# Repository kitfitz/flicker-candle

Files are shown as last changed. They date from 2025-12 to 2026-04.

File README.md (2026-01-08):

# Antique inspired candlestick holder
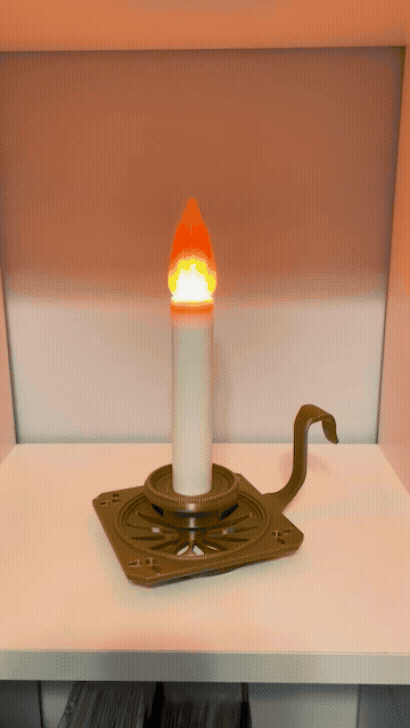
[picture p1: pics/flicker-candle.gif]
Flickering LED candle video


This project started with a restoration and modernization to an antique candlestick holder
that my grandfather made. I adoped some of the design elements as an homage to his work,
but used a style all my own. The sections below detail each aspect required to build your
own copy and a bit more about the history for those interested.

## Electrical components

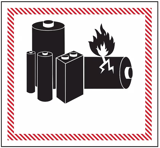
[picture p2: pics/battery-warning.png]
Battery Danger warning label

</br>**DANGER**: Lithium Ion batteries can get hot
and cause a fire!

The battery and charger used are specified to detect short conditions and overheading, but
always use caution when working with these devices!

The design choices were influenced by size and common availability. Everything is available
through Amazon, maybe other channels. The electrical components are [here](electrical/electrical.md)

The LED bulb uses a standard 12v G4 socket. There is a charger for the single LiPo cell
and a DC to DC converter to boost the battery voltage to 12v.

## 3D models

There are [six 3D printed parts](3D-cad/parts.md), designed using [OpenSCAD](https://openscad.org/).
All of the designs are my original work and I'm not a mechanical designer, so don't be
too hard on me if the models aren't great!

The parts were printed using a Prusa Research i3 MK3S using PrusaSlicer. I tend to make
models with tight clearances and sand as necessary. The inside of the bulb needed a
bit of work to make the LED fit. There isn't enough thickness to make the inside
bigger without getting into the threads. Hand filing the inside diameter was the best
solution I found.

The bulb is printed in Prusament PETG Prusa Orange transparent. The base and cup are
printed in Panchroma PLA Silk Brass. The candle, charge plate, and latch are printed in
Amolen PLA+ Paper White.

## Assembly

The candle has 14 individual parts, with assembly instructions [here](assembly/assembly.md)

## More about the history and design

In the house where I grew up, as you entered through the front door you stood in a foyer.
Towards the other end, by the hallway leading to the bedrooms, was a small round table.
On the table was a nightlight, hand crafted by my grandfather, that resembled a
candlestick holder with a candle and a neon flicker bulb on top. He likely cast the
intricate brass base piece in his basement. The family moved out of that house and in the
process of moving (multiple times), the candle holder was damaged. The handle was broken
off the base and into two pieces. Eventually the candle and electrical parts were lost.
My sister suggested that without the original parts, maybe I could make something to
replace them. The project became somewhat like what the car world calls a "restomod."
The idea being you preserve the antique style and as much of the original as makes sense
(restore), but use modern parts for the engine, brakes, handling, and so forth (modify).
In the case of an antique electric candle, that means a rechargeable battery and an LED
flicker bulb are basic requirements.

When grandad made his candle, he didn\'t make a cup. The white candle tube went all the
way to the base, with an electrical cord coming through a cutout at the bottom. My candle
design is the same form factor as a standard 7/8 in. (22mm) taper candle, which requires a
cup feature. Researching the design in different periods led to see that grandad was a
fan of the 18th Century Victorian style. The beaded ring feature is from that period and
was kept in the cup design to echo the base. The base I designed kept the beaded ring
feature, but has a simple flower theme instead of the intricate filigree of the original.
I thought bees in the corners would be a good accent to the flower.

The design of the candle constrained to the "correct" dimensions was a little challenging.
The LiPo battery cell just fits nicely with room on each side for the required wires to
pass. Finding a charger module and DC to DC module that fit inside the body of the candle
was great. Using off the shelf parts instead of designing from scratch is quite a savings
in time, effort, and cost.

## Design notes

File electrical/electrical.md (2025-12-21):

# Electrical

All of the electrical parts are all available through Amazon:

* [G4 flicker bulb](https://www.amazon.com/dp/B07VT4G6ZC?ref=ppx_yo2ov_dt_b_fed_asin_title)
* [LiPo 1000maH battery](https://www.amazon.com/dp/B0BF555H93?ref=ppx_yo2ov_dt_b_fed_asin_title&th=1)
* [G4 socket](https://www.amazon.com/dp/B0734QVL95?ref=ppx_yo2ov_dt_b_fed_asin_title&th=1)
* [JST-PH 2.0mm connector](https://www.amazon.com/dp/B07NWD5NTN?ref=ppx_yo2ov_dt_b_fed_asin_title)
<br/>I wish I had found somewhere to buy only sockets.
* [LP4056H-LiPoCharger](https://www.amazon.com/dp/B0BRXYZTWN?ref=ppx_yo2ov_dt_b_fed_asin_title&th=1)
</br>This charger employs this IC: [LP4056H.](LP4056H-LiPoCharger.pdf)
* [DC-DC converter](https://www.amazon.com/dp/B0BL7BRDYM?ref=ppx_yo2ov_dt_b_fed_asin_title)
</br>This module is based on the PWCHIP PW5300 module. Data sheets and schematics are a little hard to find.
* [Switch](https://www.amazon.com/dp/B00S4VZZR0?ref_=ppx_hzsearch_conn_dt_b_fed_asin_title_8)
* [22 AWG silicone wire](https://www.amazon.com/dp/B089D29FHC?ref_=ppx_hzsearch_conn_dt_b_fed_asin_title_9&th=1)

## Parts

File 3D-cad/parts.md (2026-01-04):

# 3D printed parts

## base (base.scad)
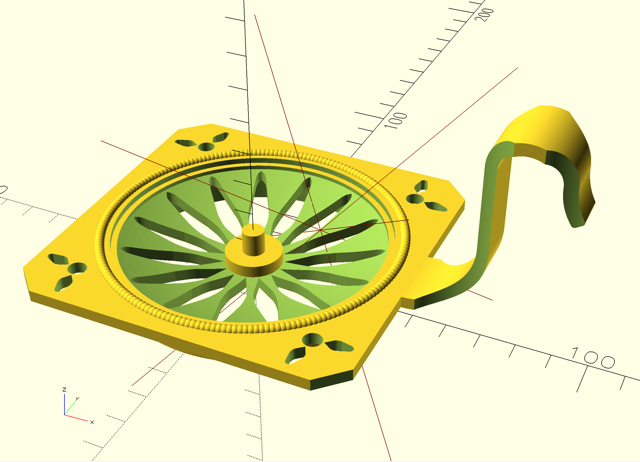
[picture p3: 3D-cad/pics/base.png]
Candlestick base rendered in OpenSCAD

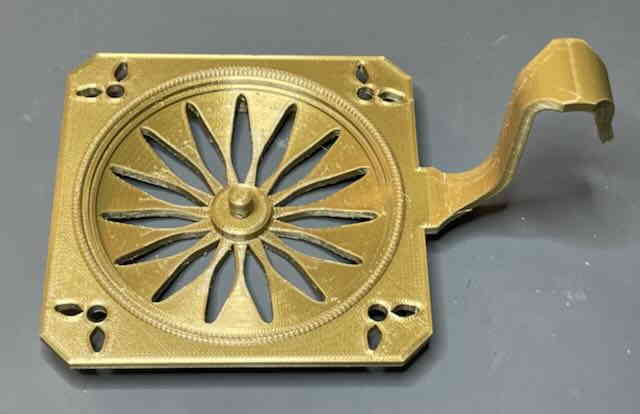
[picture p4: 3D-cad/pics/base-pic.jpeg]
3D printed candlestick base

## cup (candlestick-cup.scad)
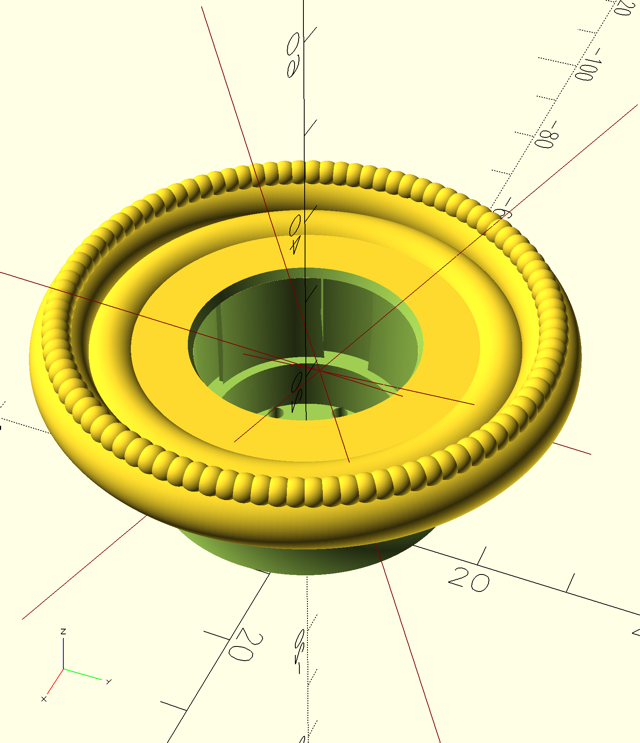
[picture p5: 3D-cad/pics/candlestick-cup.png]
Candlestick cup rendered in OpenSCAD

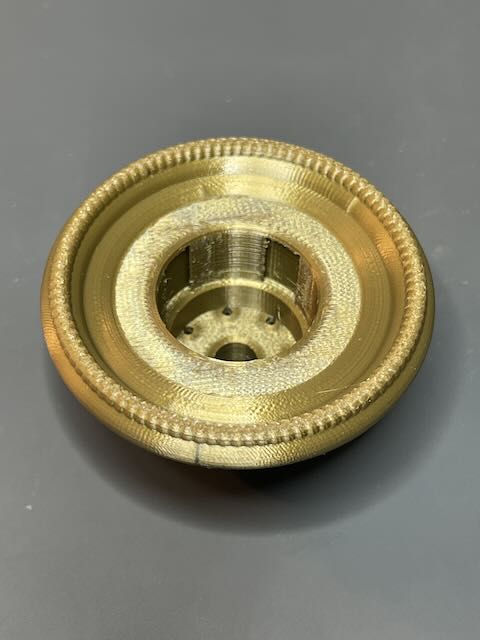
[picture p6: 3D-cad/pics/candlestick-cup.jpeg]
3D printed candlestick cup

## bulb (bulb.scad)
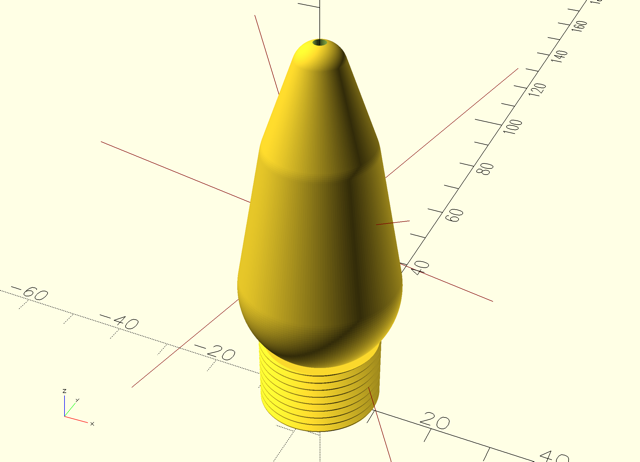
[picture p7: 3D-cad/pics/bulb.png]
Bulb rendered in OpenSCAD

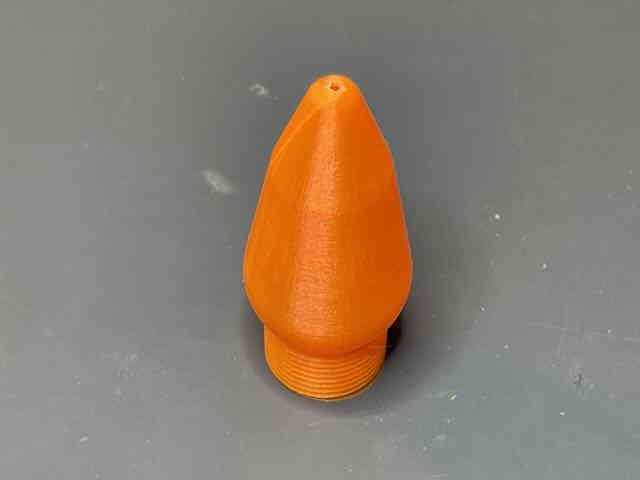
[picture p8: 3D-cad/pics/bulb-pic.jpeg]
3D printed bulb

## candle (candle.scad)
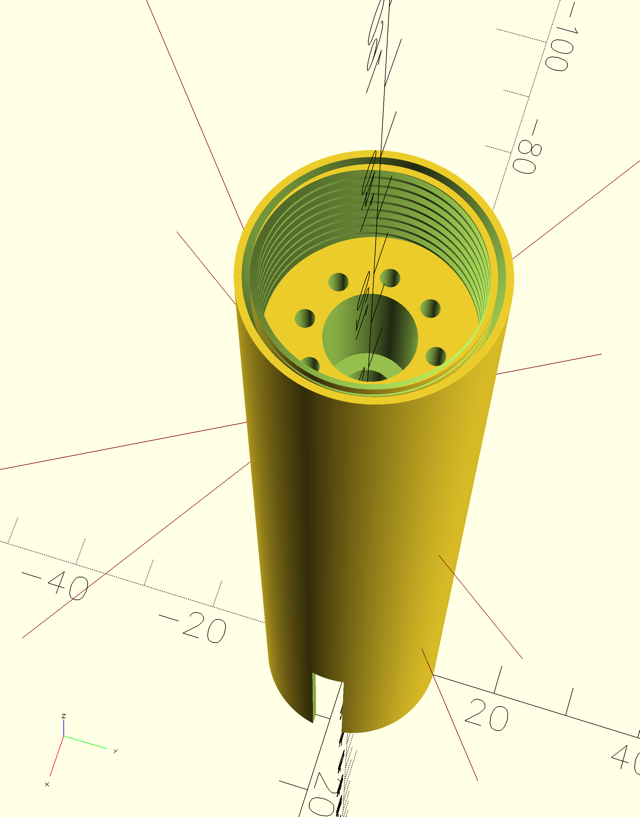
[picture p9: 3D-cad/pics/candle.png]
Candle rendered in OpenSCAD

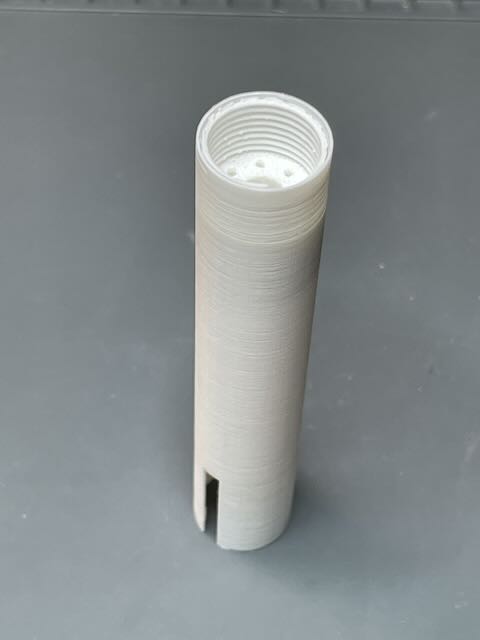
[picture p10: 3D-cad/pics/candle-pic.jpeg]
3D printed candle

## charge plate (charge-plate.scad)
Charge plate rendered in OpenSCAD
3D printed charge plate
## latch (latch.scad)
Latch rendered in OpenSCAD
3D printed latch

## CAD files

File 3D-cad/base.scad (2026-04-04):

// BSD-3-Clause License
//
// Copyright 2025 Kit Fitzpatrick
//
// Redistribution and use in source and binary forms, with or without modification, are
// permitted provided that the following conditions are met:
//
// 1. Redistributions of source code must retain the above copyright notice, this list of
//    conditions and the following disclaimer.
//
// 2. Redistributions in binary form must reproduce the above copyright notice, this list
//    of conditions and the following disclaimer in the documentation and/or other
//    materials provided with the distribution.
//
// 3. Neither the name of the copyright holder nor the names of its contributors may be
//    used to endorse or promote products derived from this software without specific
//    prior written permission.
//
// THIS SOFTWARE IS PROVIDED BY THE COPYRIGHT HOLDERS AND CONTRIBUTORS “AS IS” AND ANY
// EXPRESS OR IMPLIED WARRANTIES, INCLUDING, BUT NOT LIMITED TO, THE IMPLIED WARRANTIES
// OF MERCHANTABILITY AND FITNESS FOR A PARTICULAR PURPOSE ARE DISCLAIMED. IN NO EVENT
// SHALL THE COPYRIGHT HOLDER OR CONTRIBUTORS BE LIABLE FOR ANY DIRECT, INDIRECT,
// INCIDENTAL, SPECIAL, EXEMPLARY, OR CONSEQUENTIAL DAMAGES (INCLUDING, BUT NOT LIMITED
// TO, PROCUREMENT OF SUBSTITUTE GOODS OR SERVICES; LOSS OF USE, DATA, OR PROFITS; OR
// BUSINESS INTERRUPTION) HOWEVER CAUSED AND ON ANY THEORY OF LIABILITY, WHETHER IN
// CONTRACT, STRICT LIABILITY, OR TORT (INCLUDING NEGLIGENCE OR OTHERWISE) ARISING IN ANY
// WAY OUT OF THE USE OF THIS SOFTWARE, EVEN IF ADVISED OF THE POSSIBILITY OF SUCH DAMAGE.

//
// This model is for the base of the candlestick holder. It has the locating pin feature
// to glue the cup.
//
// -- Part of the antique candlestick holder project
//

include <candlestick-dimensions.scad>

use <torus.scad>
use <triangle.scad>
use <leaf.scad>
use <bee.scad>
use <handle.scad>

module bead_ring(ring_dia, bead_dia, count)
{
   for(i = [0:count-1])
   {
      angle = 360/count;

      rotate([0,0,i*angle])
      {
         translate([-ring_dia, 0, 0])
         {
            sphere(d=bead_dia, $fn=300);
         }
      }
   }
}


// Main bowl shape
translate([0,0,base_primary_dia/2])
{
   difference()
   {
      sphere(d=base_primary_dia, $fn=300);

      translate([ 0, 0, base_to_bot])
      {
         cube([ base_primary_dia, base_primary_dia, base_primary_dia], center=true);
      }

      translate([0,0,-base_primary_dia/2])
      {
         difference()
         {
            cylinder(h=base_to_bot+base_wall_thk, d=base_primary_dia, $fn=360);
            cylinder(h=base_to_bot+base_wall_thk, d=base_ring_dia, $fn=360);
         }
      }

      translate([0,0, base_wall_thk])
      {
         sphere(d=base_primary_dia, $fn=300);
      }

      for( angle = [0 : 24 : 360])
      {
         rotate([ 0, 0, angle])
         {
            translate([0,0,-base_primary_dia/2])
            {
               linear_extrude(height=base_to_bot, scale = 1, $fn=300)
               {
                  translate([ 0, 9, 0])
                  {
                     scale([ 0.125, 0.295, 1])
                     {
                        leaf_100mm();
                     }
                  }
               }
            }
         }
      }
   }
}

// Flat top of the bowl
translate([0, 0, base_to_bot])
{
   difference()
   {
      // Didn't want to take the bees out with the other cuts, so move it here
      difference()
      {
         cube([base_width, base_depth, base_wall_thk], center=true);

         translate([ 0, 0, -base_wall_thk/2])
         {
            // Cut out 4 bees, one in each corner
            for(angle=[45 : 90 : 315])
            {
               rotate([0,0,angle])
               {
                  translate([-(base_width/2 + 1), 0, 0])
                  {
                     scale([0.08,0.08, 1])
                     {
                        linear_extrude(height=base_wall_thk, convexity = 100)
                        {
                           bee();
                        }
                     }
                  }
               }
            }
         }
      }


      cylinder(h=base_wall_thk, d=base_ring_dia, center=true, $fn=300);

      // Left rear corner
      translate([-base_width/2, base_depth/2, -base_wall_thk/2])
      {
         rotate([0,0,-90])
         {
            triangle(base_corner_cut, base_corner_cut, base_wall_thk);
         }
      }

      // Right rear corner
      translate([base_width/2, base_depth/2, -base_wall_thk/2])
      {
         rotate([0,0,180])
         {
            triangle(base_corner_cut, base_corner_cut, base_wall_thk);
         }
      }

      // Left front corner
      translate([-base_width/2, -base_depth/2, -base_wall_thk/2])
      {
         triangle(base_corner_cut, base_corner_cut, base_wall_thk);
      }

      // Right front corner
      translate([base_width/2, -base_depth/2, -base_wall_thk/2])
      {
         rotate([0,0,90])
         {
            triangle(base_corner_cut, base_corner_cut, base_wall_thk);
         }
      }
   }
}

// Add the handle
translate([base_width/2, 0, base_to_bot - (handle_thk - base_wall_thk/2)])
{
   handle();
}

// Add a pad to match the handle thickness
difference()
{
   translate([base_width/2-handle_pad_depth, -handle_wide_width/2, (base_to_bot -base_wall_thk/2) - handle_pad_thk])
   {
      cube([handle_pad_depth, handle_wide_width, handle_pad_thk]);
   }

   cylinder(h=base_to_bot, d=base_ring_dia);
}

// Beads around the main bowl
translate([ 0, 0, base_to_bot-bead_dia/2])
{
   translate([0, 0, bead_dia])
   {
      bead_ring(base_ring_dia/2+bead_dia, bead_dia, 200);
   }
}

// Base ring
difference()
{
   cylinder(h=base_to_bot, d=base_ring_dia, $fn=300);
   cylinder(h=base_to_bot, d=base_ring_dia-base_ring_thk, $fn=300);
}

// Center pin
translate([ 0, 0, base_wall_thk])
{
   cylinder(h=base_pedestal_height, d=cup_bot_dia, $fn=200);

   translate([ 0, 0, base_pedestal_height])
   {
      // Ensure clearance
      cylinder(h=bolt_len, d=bolt_dia - 0.2, $fn=200);
   }
}

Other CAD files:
3D-cad/bee.scad
3D-cad/bulb.scad
3D-cad/candle.scad
3D-cad/candlestick-cup.scad
3D-cad/candlestick-dimensions.scad
3D-cad/charge-plate.scad
3D-cad/handle.scad
3D-cad/latch.scad
3D-cad/leaf.scad
3D-cad/threads.scad
3D-cad/torus.scad
3D-cad/triangle.scad

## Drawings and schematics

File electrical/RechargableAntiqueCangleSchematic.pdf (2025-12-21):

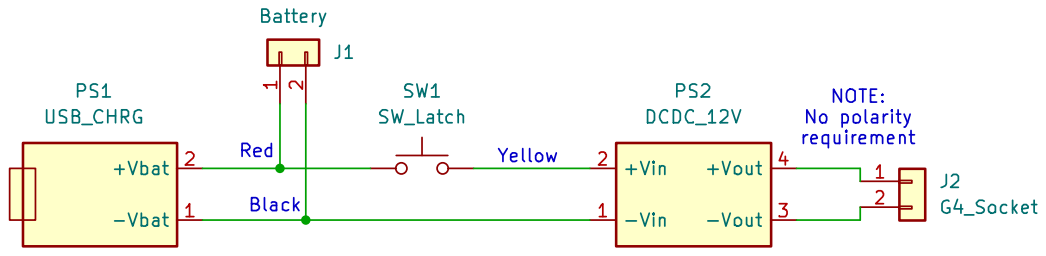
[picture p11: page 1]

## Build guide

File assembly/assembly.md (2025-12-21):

# How to assemble the candle

## These are the parts you will need

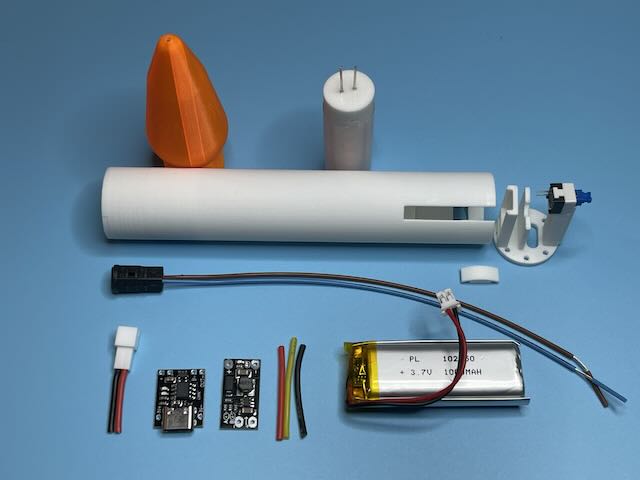
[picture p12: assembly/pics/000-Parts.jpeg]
The 14 parts required

* 3D printed bulb
* LED bulb
* Candle
* Charge plate
* Switch
* Latch
* G4 socket
* JST socket
* USB charger
* DC-DC converter
* 30mm Red silicone wire
* 30mm Yellow silicone wire
* 30mm Black silicone wire
* 1000maH battery

## Step 1 - Modification of the DC-DC module (optional)
This module has an LED indicator when it is powered. If you don't want to have the LED
shining inside the candle, a simple rework disables it. Remove the resistor next to the
negative output pad. NOTE: You can mechanically remove the resistor with a flush cutter
or knife if you are careful.

### Unmodified:
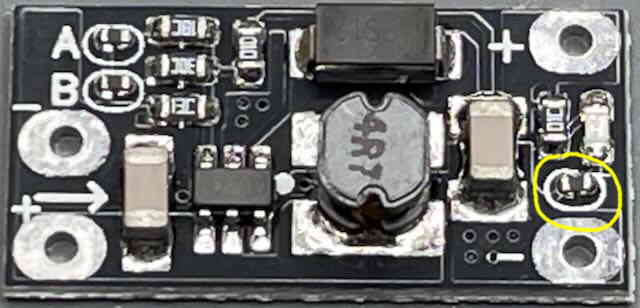
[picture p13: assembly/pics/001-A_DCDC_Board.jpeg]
Unmodified module


### Resistor removed:
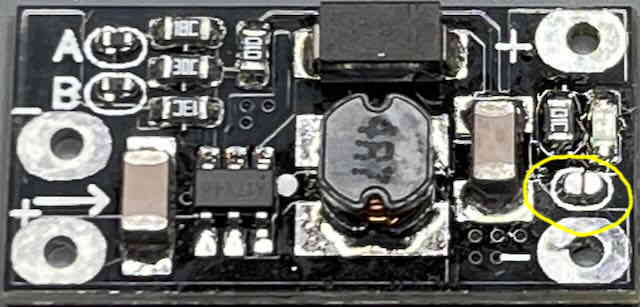
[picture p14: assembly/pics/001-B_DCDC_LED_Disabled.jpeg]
Resistor removed


## Continue assembly with the steps below:

### Step 2- Solder the JST socket to the USB charger module as well as the Red and Black wires.
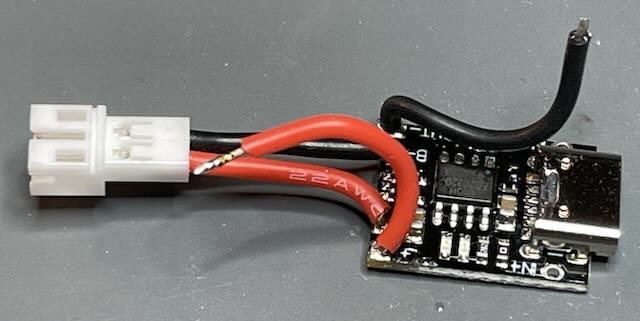
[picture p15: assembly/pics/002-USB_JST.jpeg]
step 2 wire USB charger


### Step 3 - Solder the DC-DC converter input wires.
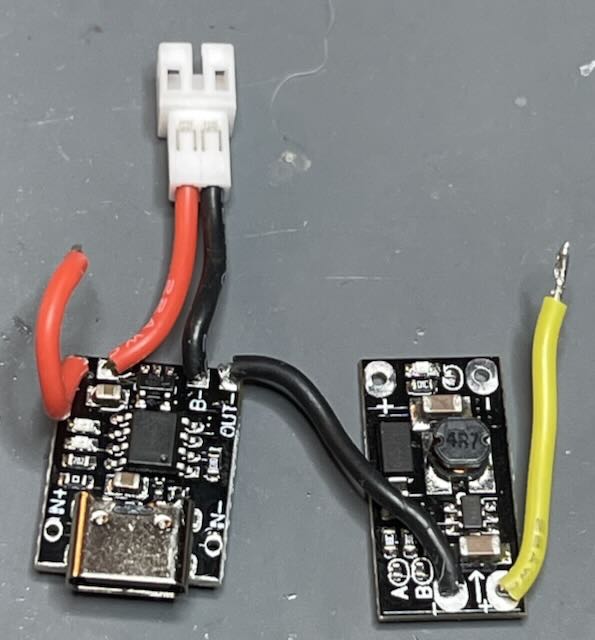
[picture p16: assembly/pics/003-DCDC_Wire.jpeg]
step 3 wire DC to DC module


### Step 4 - Insert the G4 socket as shown.

The socket needs enough slack to allow securing it with glue below. Bending the wires into
an "S" shape will help to take up the slack in the wires as the charge plate is attached.

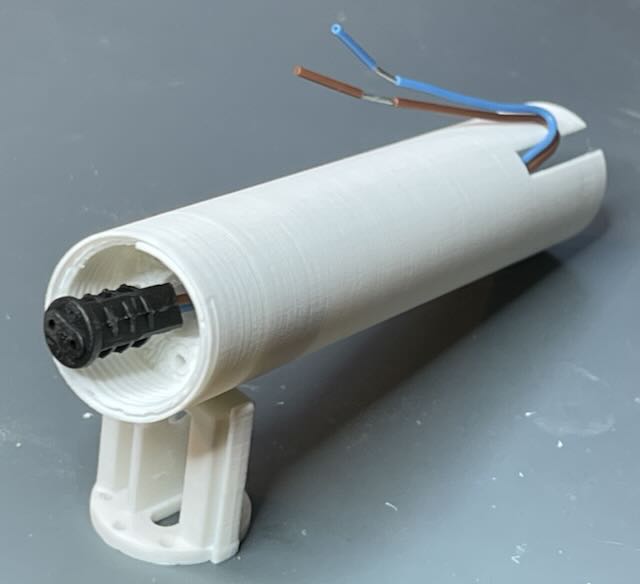
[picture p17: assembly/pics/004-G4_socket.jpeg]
step 4 insert G4 socket


### Step 5 - Attach switch

Use superglue to attach the switch to the charge plate, being careful to align the body
with the post.

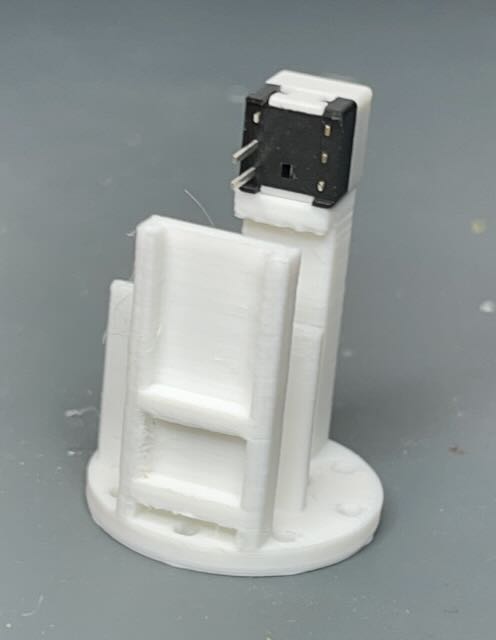
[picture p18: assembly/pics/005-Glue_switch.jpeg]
step 5 attach switch


### Step 6 - Install boards

Start with the DC-DC converter board.

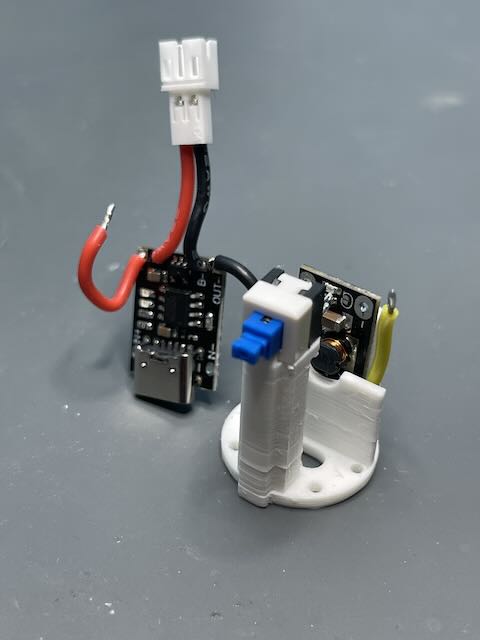
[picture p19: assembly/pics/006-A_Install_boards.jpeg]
step 6 install boards, view A


Then position the USB-C connector in the charger plate and snap the board into the post.

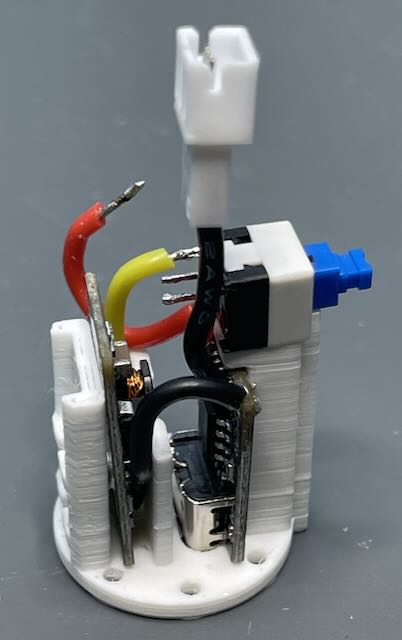
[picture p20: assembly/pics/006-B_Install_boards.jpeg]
step 6 install boards, view B


### Step 7 - Wire the switch

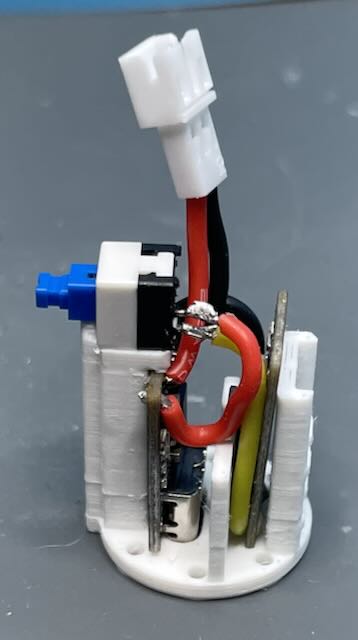
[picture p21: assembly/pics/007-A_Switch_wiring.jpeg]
step 7 wire the switch, view A


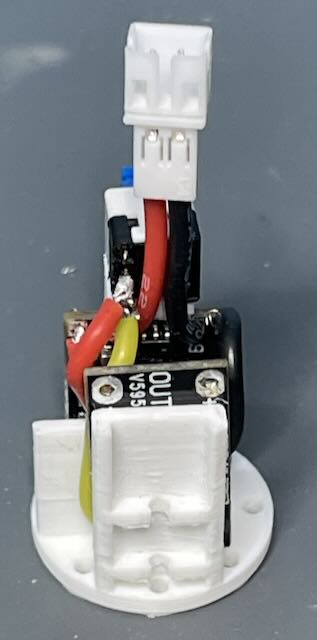
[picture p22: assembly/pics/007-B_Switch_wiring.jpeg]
step 7 wire the switch, view B


### Step 8 - Glue the G4 socket

Holding the socket out of the way (and not getting burned!), squirt a blob of hot glue
into the socket hole and quickly push in the socket and seat it.

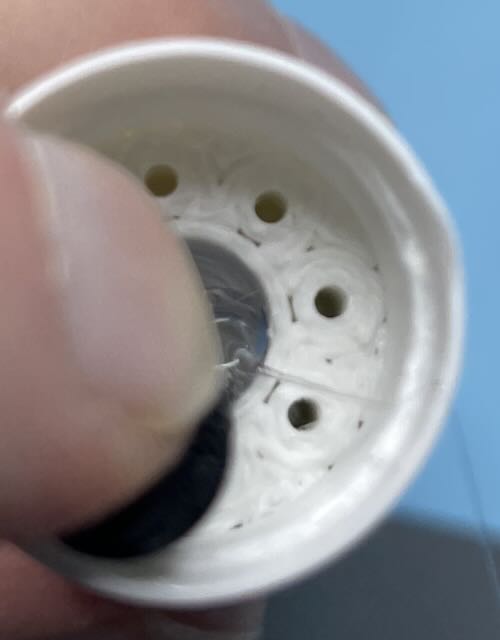
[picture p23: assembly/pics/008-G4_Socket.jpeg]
step 8 hot glue the G4 socket


### Step 9 - Hot glue switch

Use hot glue to cover the switch posts, the JST wires, and the top of the USB charger module.

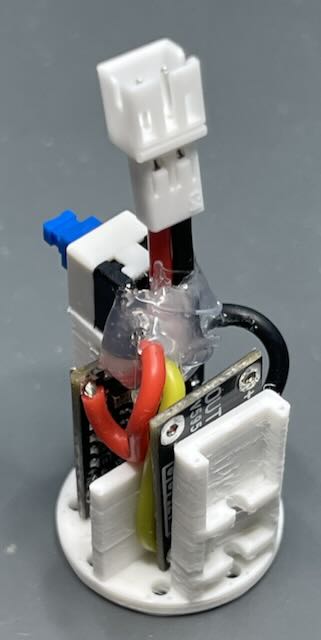
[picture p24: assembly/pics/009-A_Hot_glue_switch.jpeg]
step 9 hot glue switch view A


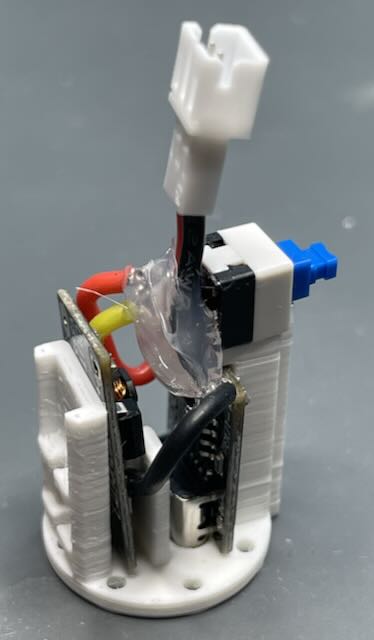
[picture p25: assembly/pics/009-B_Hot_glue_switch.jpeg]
step 9 hot glue switch view B


### Step 10 - Wire the G4 socket

Solder the Brown and Blue wires to the DC-DC converter module. Note that the colors don't
matter, the socket and LED bulb don't have a required polarity.

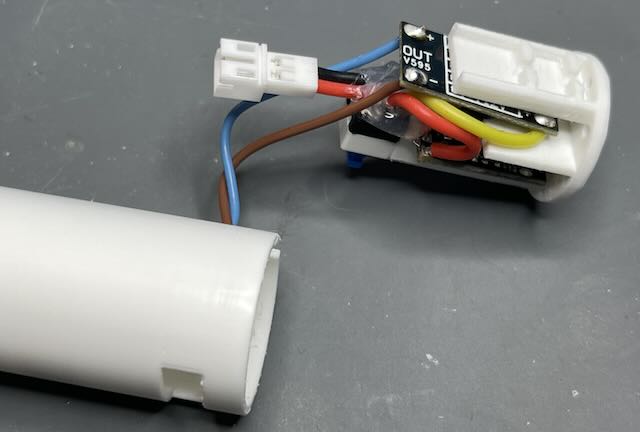
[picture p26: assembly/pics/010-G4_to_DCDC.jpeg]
step 10 wire the G4 socket


### Step 11 - Try it out!

Insert the LED bulb into the socket and attach the battery. Turn the switch on and off
a few times to ensure it is working.

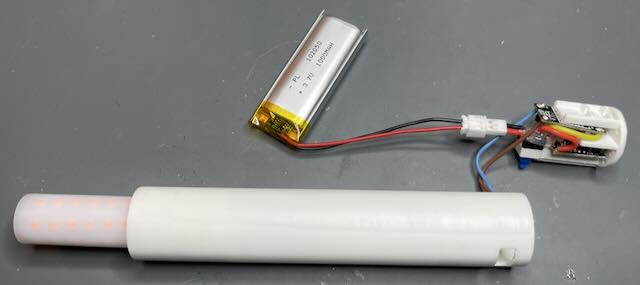
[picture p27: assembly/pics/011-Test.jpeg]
step 11 try it out


### Step 12 - Route the wires

Holding the wires to the side with the cutout, insert the battery as shown. The wires
should be on one side, along with the JST connection. Note the "S" bend in the G4
socket wire will help take up the slack when inserting the charge plate.

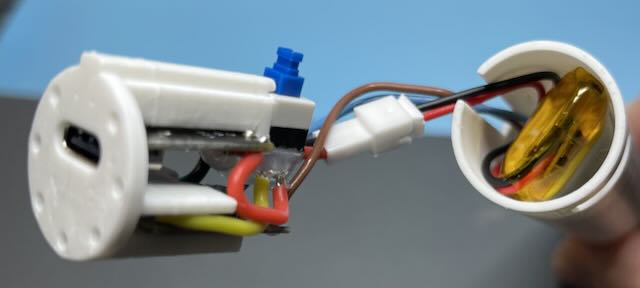
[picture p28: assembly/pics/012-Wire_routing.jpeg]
step 12 route the wires


### Step 13 - Insert the charge plate

Slide the charge plate post along the candle cutout until the bottom of the charge plate
is flush with the bottom of the candle. The charge plate slot should line up with the
latch plate slot in the candle.

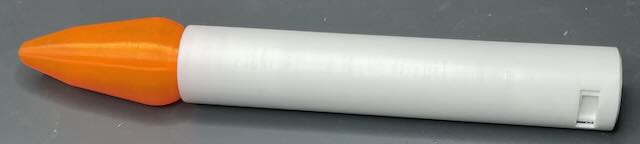
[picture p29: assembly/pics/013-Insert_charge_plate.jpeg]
step 13 insert the charge plate


### Install the latch

Install the latch starting with one side to make sure the slots are aligned. Note: Make
sure the slots don't have leftover filament blobs and printed the proper size. Otherwise
it might not be possible to install the latch.

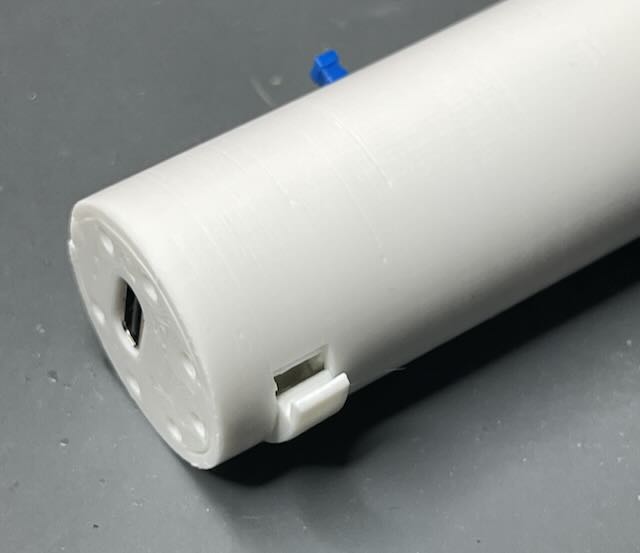
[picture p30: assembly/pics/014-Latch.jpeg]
step 14


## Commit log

2025-12-21 Initial project commit.
    [base.scad, bee.scad, bulb.scad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]
2025-12-21 Fix linked file names for case sensitive file systems.
2025-12-22 Add pics of most of the printed parts. Markup the DC to DC board pics to highlight the resistor.
2026-01-04 Add pictures of the 3D printed parts.
2026-01-08 Add an HTML page break for better printing.
2026-04-04 Improve the handle, made it thicker and a more comfortable size for fingers.
    [base.scad, candlestick-dimensions.scad]
